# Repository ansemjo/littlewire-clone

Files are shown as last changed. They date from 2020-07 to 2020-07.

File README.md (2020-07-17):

# littlewire-clone

This is a clone of [Little Wire](https://littlewire.github.io/) by Ihsan Kehribar
with mostly SMD parts.

The special part about it is that it uses a female ICSP header soldered
on the edge of the board, which can be plugged into the target device
directly or used with "pogo-pin" adapters like
[the one by Pnoxi](https://www.tindie.com/products/pnoxi/avr-isp-pogo-pin-adapter-2x3-idc2x3-pogo-254mm/).

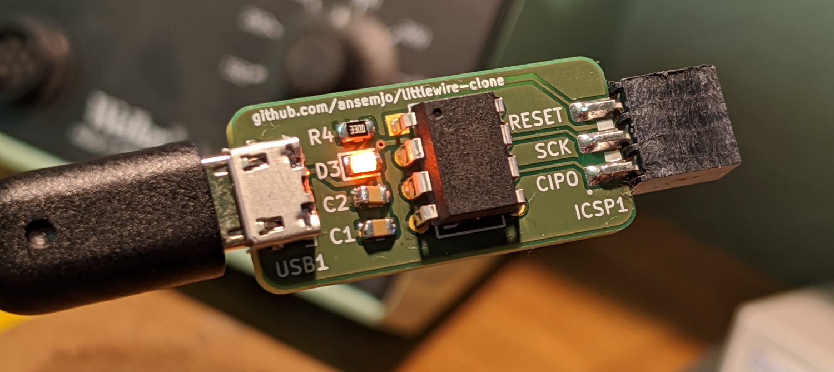
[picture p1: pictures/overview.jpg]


*Yes, I know my C2 is crooked .. Next time I'll use the "elongated pads" footprint.*

## Project structure

There's a number of interesting subdirectories, in order of applicability:

| Directory | Description |
| --- | --- |
| [`hardware`](hardware/) | The KiCad 5.1.6 project with schematics and manufacturing files for PCB production. |
| [`bootloader`](bootloader/) | Instructions on how to put the `micronucleus` bootloader onto the chip once it's assembled. |
| [`firmware`](firmware/) | A vendored copy of the Little Wire / `usbtiny` source code to install the firmware.

## First batch

I have ordered the first batch thorugh [aisler.net](https://aisler.net/). From those
I have now assembled and tested two boards.

Currently I have **6** circuit boards left. Shoot me a
[message](https://twitter.com/ansemjo) if you want one of those.

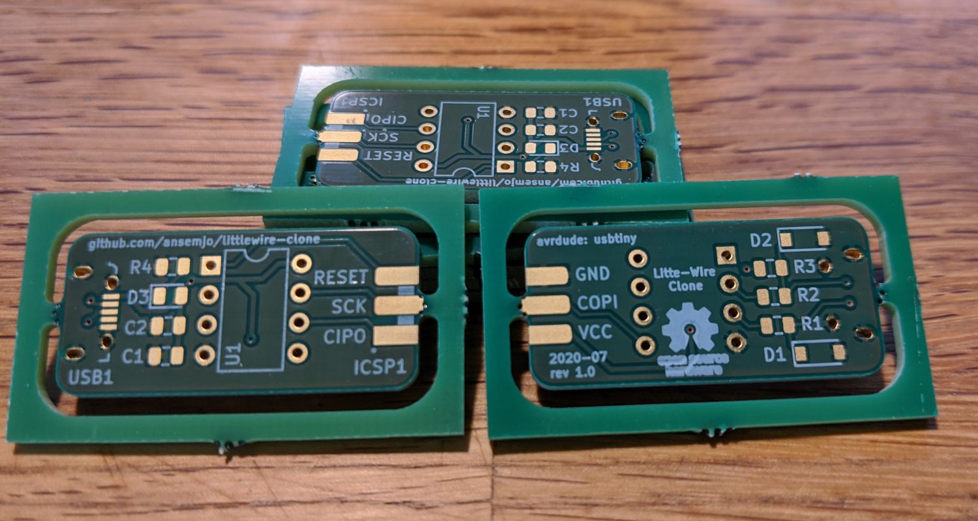
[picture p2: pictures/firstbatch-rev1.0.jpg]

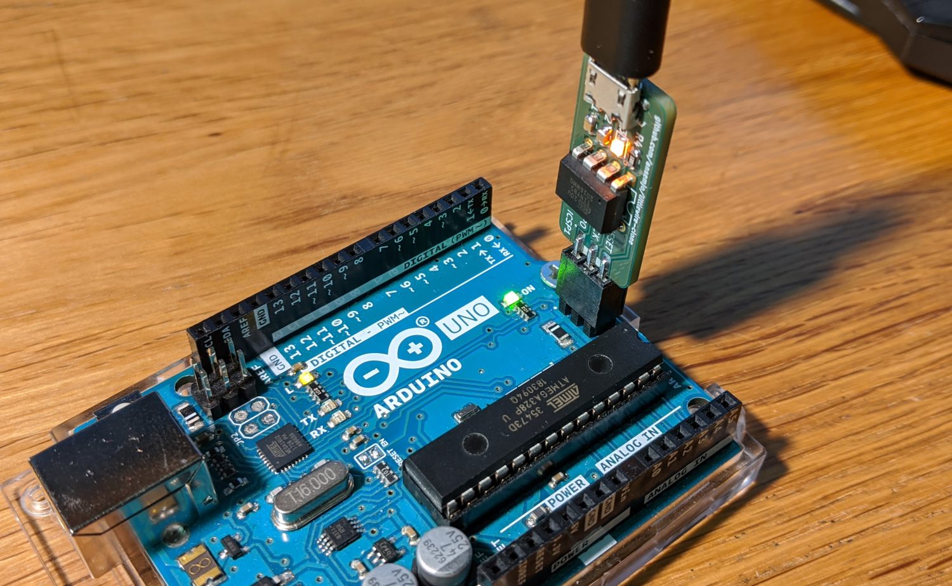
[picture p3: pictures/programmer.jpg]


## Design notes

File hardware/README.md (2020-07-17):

# Little Wire Clone

This directory describes a KiCad 5.1.6 project directory for my clone of
the Little Wire project by Ihsan Kehribar.

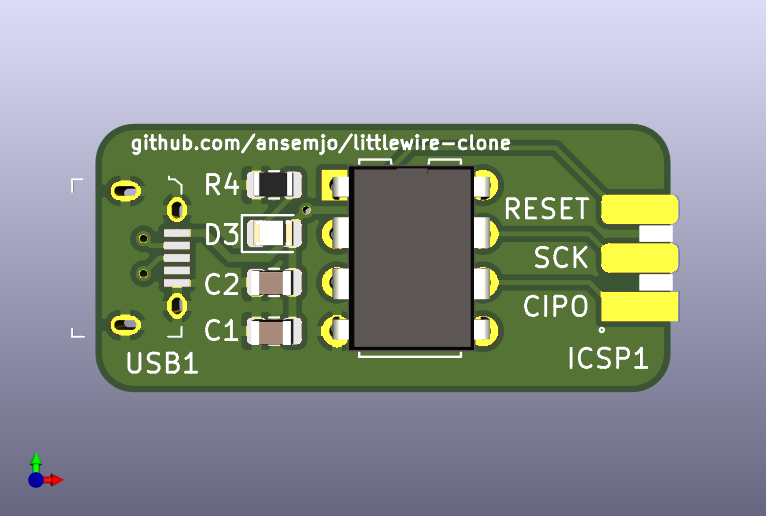
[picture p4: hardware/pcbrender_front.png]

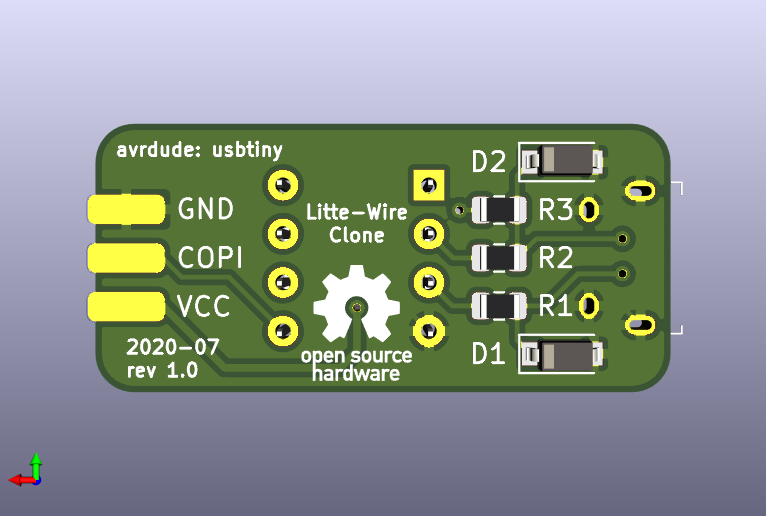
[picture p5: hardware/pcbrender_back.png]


## Bill of Materials

Here is an informal BOM with the parts I used for my two boards so far.
Note that some of the values don't match with the schematic; I used some parts
that I had available from previous orders where it shouldn't make too much of
a difference anyway.

| ref | amount | partno | name |
| --- | --- | --- | ---- |
| U1 | 1 | ATTINY85-20PU | Microchip Technology ATTINY85-20PU IC MCU 8BIT 8KB FLASH 8DIP |
| USB1 | 1 | 10118194-0001LF | Amphenol ICC CONN RCPT USB2.0 MICRO B SMD R/A |
| C1, C2 | 2 | CL21B104KACNNNC | Samsung CAP CER 0.1UF 25V X7R 0805 |
| D1, D2 | 2 | MMSZ4684T1G | ON Semiconductor DIODE ZENER 3.3V 500MW SOD123 |
| D3 | 1 | LTST-C171AKT | Lite-On Inc. LED ORANGE CLEAR SMD |
| R1, R2 | 2 | RC0805FR-07100RL | Yageo RES SMD 100 OHM 1% 1/8W 0805 |
| R3 | 1 | RC0805FR-072K2L | Yageo RES SMD 2.2K OHM 1% 1/8W 0805 |
| R4 | 1 | RC0805FR-07330RL | Yageo RES SMD 330 OHM 1% 1/8W 0805 |
| ICSP1 | 1 | SSQ-103-01-T-D | Samtec Inc. CONN RCPT 6POS 0.1 TIN PCB |

## LICENSE

Copyright (c) 2020 Anton Semjonov

This source describes Open Hardware and is licensed under the CERN-OHL-P v2

You may redistribute and modify this documentation and make products using it
under the terms of the CERN-OHL-P v2 (https:/cern.ch/cern-ohl). This
documentation is distributed WITHOUT ANY EXPRESS OR IMPLIED WARRANTY, INCLUDING
OF MERCHANTABILITY, SATISFACTORY QUALITY AND FITNESS FOR A PARTICULAR PURPOSE.
Please see the CERN-OHL-P v2 for applicable conditions.

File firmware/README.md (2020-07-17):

# LittleWire Firmware

This is the `firmware/` subdirectory from Ihsan Kehribar's project at
[github.com/littlewire/Little-Wire](https://github.com/littlewire/Little-Wire).

It is simply downloaded from commit [d918a4b](https://github.com/littlewire/Little-Wire/commit/d918a4ba1ccae27ef02997fd5512054f45110619)
and vendored in full. No files were modified by me. It is therefore the
**Little Wire Release v1.3**.

For more information and compatible software libraries checkout his page
at [littlewire.github.io](https://littlewire.github.io/)!

## Flashing

Have you completed the steps to flash and test the `micronucleus` bootloader
in [../bootloader](../bootloader/README.md)?

Compile the firmware file `main.hex` and use the `micronucleus` commandline
to flash it over USB:

    make hex
    micronucleus main.hex

Done!

## Using with `avrdude`

It is written on the circuit board silkscreen so you can never forget the
programmer option: it is `usbtiny`.

On the top side there are two small patches of white silkscreen between the
ICSP header pins. That is representing the "notch" on 6-pin ICSP cables. Here
you can see me flashing an Arduino Uno:

    avrdude -c usbtiny -p m328p -U blink.hex



## Note on `udev` rules

On Linux you'll either need to use `sudo ..` for your commands or add a
ruleset to `udev` to allow accessing Little-Wire's USB port. The following
snippet assumes that your user is member of the `plugdev` group and shall be
placed in `/etc/udev/rules.d/49-usbtiny-programmer.rules` for example:

    # allow writing to usbtiny programmers
    SUBSYSTEMS=="usb", ATTRS{idVendor}=="1781", ATTRS{idProduct}=="0c9f", MODE:="0660", GROUP="plugdev"

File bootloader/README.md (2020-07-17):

# Flashing the `micronucleus` bootloader

The `micronucleus` project is a bootloader that uses the same V-USB stack by
Objective Development that the `usbtiny` firmware uses. This is convenient
because once everthing is soldered in place you ideally do not want to attach
testclips or anything like that to program your ATtiny over ISP every time.
Also, since we need to ultimately disable the Reset pin in order to use it as
an additional IO pin, we won't be able to program it without a high-voltage
programmer anyway.

Briefly, the steps are:

* Flash a default micronucleus configuration and set the required fuses to see
  if the stack works and you can program the ATtiny over USB
* Flash the slightly customized `t85_littlewire` configuration
* Disable the external Reset pin with a fuse setting
* Continue programming the actual firmware over USB

## Obtain the `micronucleus` source code

You can checkout the submodule in `./micronucleus` or download an extract an
archive from GitHub yourself:

    git submodule update --init micronucleus/

Now enter the subdirectory `firmware/` of micronuleus for all following commands:

    cd micronucleus/firmware/

## Flash the default `t85_default` configuration

The pinout on the `littlewire` is compatible with the default configuration for the
ATtiny85. Therefore just use the `t85_default` configuration at first. Build the
firmware, flash it and set the fuses for the correct clock settings etc.

You'll need an ISP programmer for this but you can use any existing programmer with
a couple of jumper wires. The ICSP pins of the ATtiny are conveniently laid out for
you. :P

    make CONFIG=t85_default PROGRAMMER="-c ft232h" flash
    make CONFIG=t85_default PROGRAMMER="-c ft232h" fuse

Substitute the `PROGRAMMER` variable according to the one you're using. I have an
alias in my `~/.avrduderc` for an FTDI FT232H based one here.

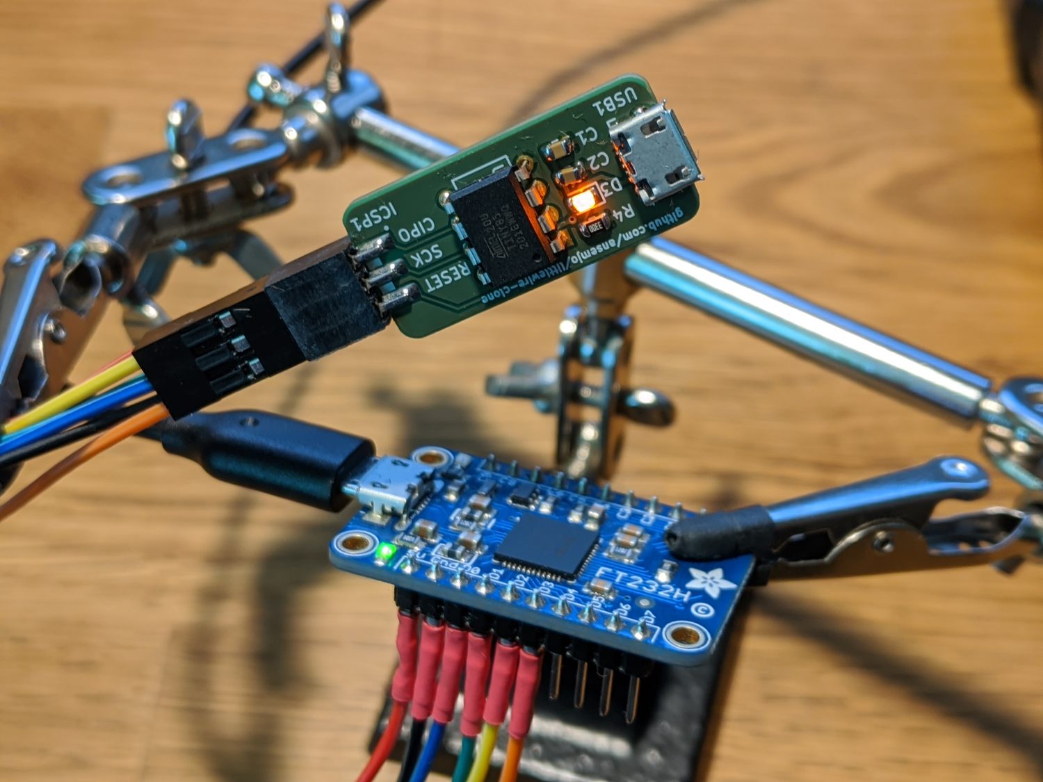
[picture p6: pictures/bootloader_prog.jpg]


## Check if the bootloader is working

Connect a USB cable and check if the device is recognized. On Windows you'll likely
need some drivers first. Try erasing the chip through the bootloader:

    micronucleus --erase-only

## Flash the custom `t85_littlewire` configuration and disable Reset pin

Everything OK? Good. Now we need to disable the Reset pin.

However, there still needs to be a way to enter the bootloader when the `littlewire`
firmware is flashed. By default, `micronucleus` *always* starts and then chainloads
the actual firmware after something like 6 seconds. Meh.

With a little change to the `#define ENTRYMODE ..` we can use a jumper pin, that needs
to be pulled low on power-up to enter the bootloader. I think using the Reset pin `PB5`
is fitting here.

Modify the default config or just link / copy the prepared configuration in `t85_littlewire`:

    ln -sr ../../t85_littlewire configuration/

And repeat the `flash` command above with the new config:

    make CONFIG=t85_littlewire PROGRAMMER="-c ft232h" flash

As long as there is no actual firmware on the ATtiny85 it will always enter the
`micronucleus` bootloader unconditionally. To make the Reset pin available, finally
set the high fuse to disable it:

    make CONFIG=t85_littlewire PROGRAMMER="-c ft232h" disablereset

**After this command you won't be able to program the chip over ISP anymore.** That's why
you should make sure that the bootloader works first.

Now continue with the firmware. If you need to enter the bootloader later, either use a
two-pin jumper in the female ICSP header or use tweezers to short pins 1 and 4 before
connecting the USB cable:

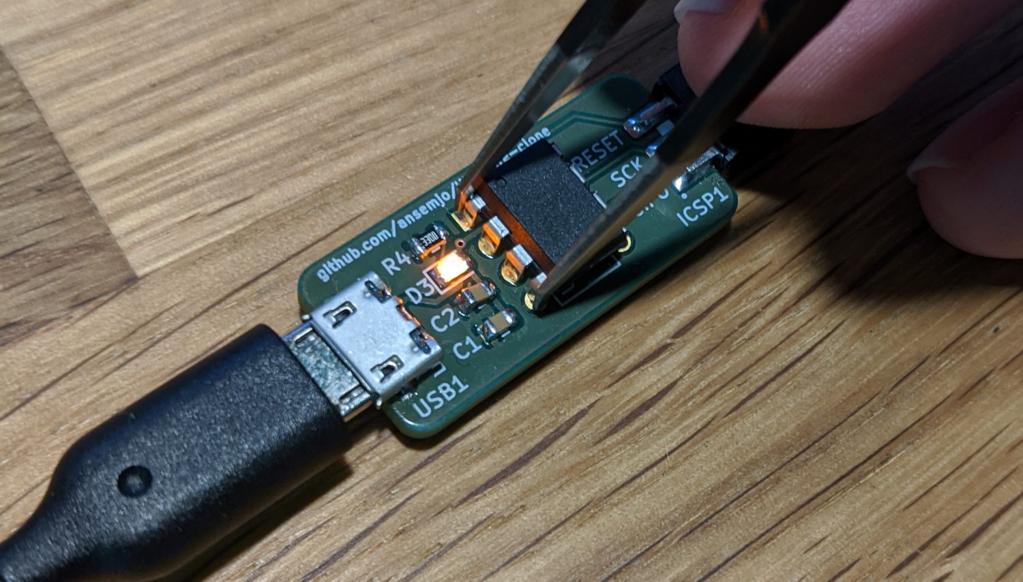
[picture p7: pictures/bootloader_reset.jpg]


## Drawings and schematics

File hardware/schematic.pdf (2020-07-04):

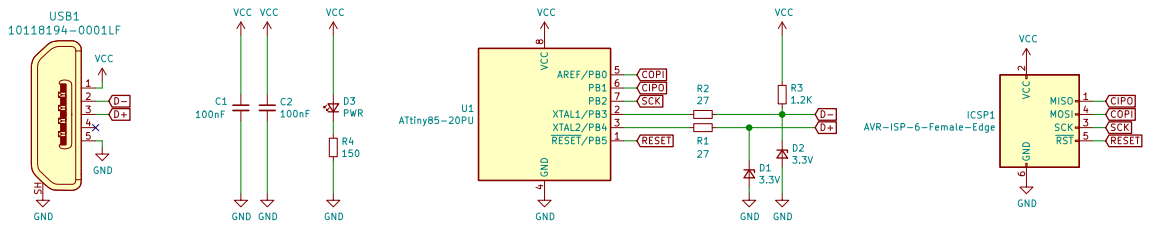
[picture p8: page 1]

2 SCK 3 MOSI 4 RST 5 GND

File: lwclone.sch Sheet: / ansemjo

Id: 1/1 Title: Little-Wire Clone

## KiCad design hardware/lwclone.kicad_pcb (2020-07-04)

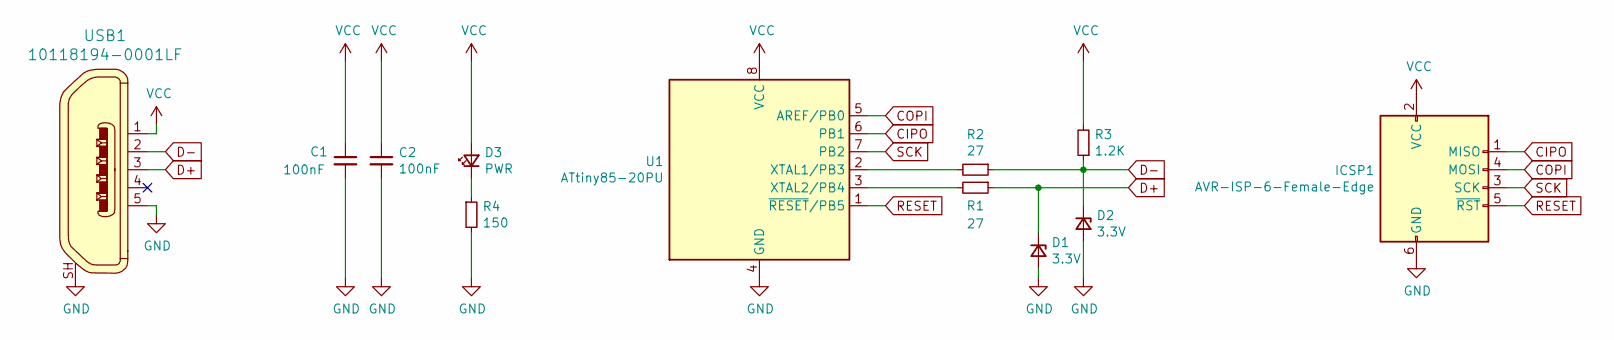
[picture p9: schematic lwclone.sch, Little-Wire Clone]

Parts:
C1, C2: 100nF; C_0805_2012Metric
D1, D2: 3.3V; D_SOD-123
D3: PWR; LED_0805_2012Metric
ICSP1: AVR-ISP-6-Female-Edge; IDC-Edge-Header-Female_2x03_P2.54mm
R1, R2: 27; R_0805_2012Metric
R3: 1.2K; R_0805_2012Metric
R4: 150; R_0805_2012Metric
U1: ATtiny85-20PU; DIP-8_W7.62mm
USB1: 10118194-0001LF; USB_Micro_B_Female_10118194-0001LF; MPN 10118194-0001LF; Digi-Key_PN 609-4618-1-ND

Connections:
CIPO: ICSP1.1 (MISO), U1.6 (PB1)
COPI: ICSP1.4 (MOSI), U1.5 (AREF/PB0)
D+: D1.1 (K), R1.1, USB1.3
D-: D2.1 (K), R2.1, R3.1, USB1.2
GND: C1.2, C2.2, D1.2 (A), D2.2 (A), ICSP1.6 (GND), R4.2, U1.4 (GND), USB1.5, USB1.SH
unnamed: D3.1 (K), R4.1
unnamed: R1.2, U1.3 (XTAL2/PB4)
unnamed: R2.2, U1.2 (XTAL1/PB3)
RESET: ICSP1.5 (~RST), U1.1 (~RESET~/PB5)
SCK: ICSP1.3 (SCK), U1.7 (PB2)
VCC: C1.1, C2.1, D3.2 (A), ICSP1.2 (VCC), R3.2, U1.8 (VCC), USB1.1

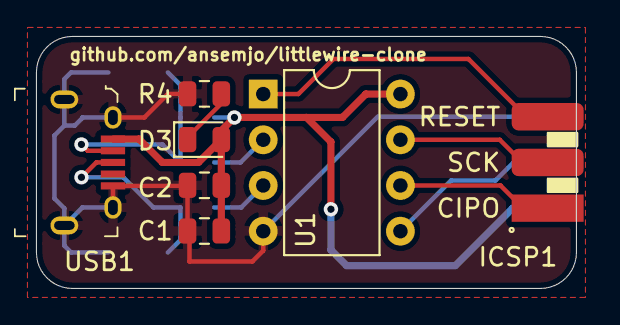
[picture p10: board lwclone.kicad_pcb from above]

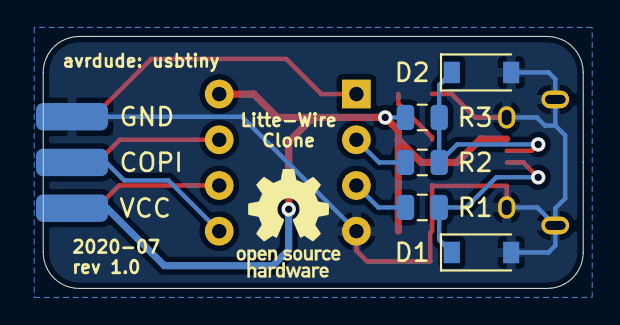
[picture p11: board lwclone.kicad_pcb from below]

Board: 2 copper layers, 30.0 x 14.0 mm, 12 parts (5 on the bottom side), 11 nets.

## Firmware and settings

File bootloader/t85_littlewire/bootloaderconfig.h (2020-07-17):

/* Name: bootloaderconfig.h
 * Micronucleus configuration file. 
 * This file (together with some settings in Makefile.inc) configures the boot loader
 * according to the hardware.
 * 
 * Controller type: ATtiny 85 - 16.5 MHz
 * Configuration:   Default configuration
 *       USB D- :   PB3
 *       USB D+ :   PB4
 *       Entry  :   Always
 *       LED    :   None
 *       OSCCAL :   Stays at 16 MHz
 * Note: Uses 16.5 MHz V-USB implementation with PLL
 * Last Change:     Mar 16,2014
 *
 * License: GNU GPL v2 (see License.txt
 */
#ifndef __bootloaderconfig_h_included__
#define __bootloaderconfig_h_included__

/* ------------------------------------------------------------------------- */
/*                       Hardware configuration.                             */
/*      Change this according to your CPU and USB configuration              */
/* ------------------------------------------------------------------------- */

#define USB_CFG_IOPORTNAME      B
  /* This is the port where the USB bus is connected. When you configure it to
   * "B", the registers PORTB, PINB and DDRB will be used.
   */

#define USB_CFG_DMINUS_BIT      3
/* This is the bit number in USB_CFG_IOPORT where the USB D- line is connected.
 * This may be any bit in the port.
 */
#define USB_CFG_DPLUS_BIT       4
/* This is the bit number in USB_CFG_IOPORT where the USB D+ line is connected.
 * This may be any bit in the port, but must be configured as a pin change interrupt.
 */

#define USB_CFG_CLOCK_KHZ       (F_CPU/1000)
/* Clock rate of the AVR in kHz. Legal values are 12000, 12800, 15000, 16000,
 * 16500, 18000 and 20000. The 12.8 MHz and 16.5 MHz versions of the code
 * require no crystal, they tolerate +/- 1% deviation from the nominal
 * frequency. All other rates require a precision of 2000 ppm and thus a
 * crystal!
 * Since F_CPU should be defined to your actual clock rate anyway, you should
 * not need to modify this setting.
 */

/* ------------- Set up interrupt configuration (CPU specific) --------------   */
/* The register names change quite a bit in the ATtiny family. Pay attention    */
/* to the manual. Note that the interrupt flag system is still used even though */
/* interrupts are disabled. So this has to be configured correctly.             */


// setup interrupt for Pin Change for D+
#define USB_INTR_CFG            PCMSK
#define USB_INTR_CFG_SET        (1 << USB_CFG_DPLUS_BIT)
#define USB_INTR_CFG_CLR        0
#define USB_INTR_ENABLE         GIMSK
#define USB_INTR_ENABLE_BIT     PCIE
#define USB_INTR_PENDING        GIFR
#define USB_INTR_PENDING_BIT    PCIF
#define USB_INTR_VECTOR         PCINT0_vect

/* ------------------------------------------------------------------------- */
/*       Configuration relevant to the CPU the bootloader is running on      */
/* ------------------------------------------------------------------------- */

// how many milliseconds should host wait till it sends another erase or write?
// needs to be above 4.5 (and a whole integer) as avr freezes for 4.5ms
#define MICRONUCLEUS_WRITE_SLEEP 5


/* ---------------------- feature / code size options ---------------------- */
/*               Configure the behavior of the bootloader here               */
/* ------------------------------------------------------------------------- */

/*
 *  Define Bootloader entry condition
 * 
 *  If the entry condition is not met, the bootloader will not be activated and the user program
 *  is executed directly after a reset. If no user program has been loaded, the bootloader
 *  is always active.
 * 
 *  ENTRY_ALWAYS        Always activate the bootloader after reset. Requires the least
 *                      amount of code.
 *
 *  ENTRY_WATCHDOG      Activate the bootloader after a watchdog reset. This can be used
 *                      to enter the bootloader from the user program.
 *                      Adds 22 bytes.
 *
 *  ENTRY_EXT_RESET     Activate the bootloader after an external reset was issued by 
 *                      pulling the reset pin low. It may be necessary to add an external
 *                      pull-up resistor to the reset pin if this entry method appears to
 *                      behave unreliably.
 *                      Adds 22 bytes.
 *
 *  ENTRY_JUMPER        Activate the bootloader when a specific pin is pulled low by an 
 *                      external jumper. 
 *                      Adds 34 bytes.
 *
 *       JUMPER_PIN     Pin the jumper is connected to. (e.g. PB0)
 *       JUMPER_PORT    Port out register for the jumper (e.g. PORTB)  
 *       JUMPER_DDR     Port data direction register for the jumper (e.g. DDRB)  
 *       JUMPER_INP     Port inout register for the jumper (e.g. PINB)  
 * 
 */

#define ENTRYMODE ENTRY_JUMPER

#define JUMPER_PIN    PB5
#define JUMPER_PORT   PORTB 
#define JUMPER_DDR    DDRB 
#define JUMPER_INP    PINB 
 
/*
  Internal implementation, don't change this unless you want to add an entrymode.
*/
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

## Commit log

2020-07-04 commit first revision ordered on aisler.net
    [lwclone.kicad_pcb, lwclone.sch]
2020-07-04 copy all used symbols to local lwclone.lib
    [lwclone.kicad_pcb, lwclone.sch]
2020-07-04 move files to hardware subdirectory
    [lwclone.kicad_pcb, lwclone.sch]
2020-07-04 add schematic pdf, pcb renders, first readme
2020-07-15 add pictures of arrived pcbs
2020-07-17 add a bill of materials table in hardware README
